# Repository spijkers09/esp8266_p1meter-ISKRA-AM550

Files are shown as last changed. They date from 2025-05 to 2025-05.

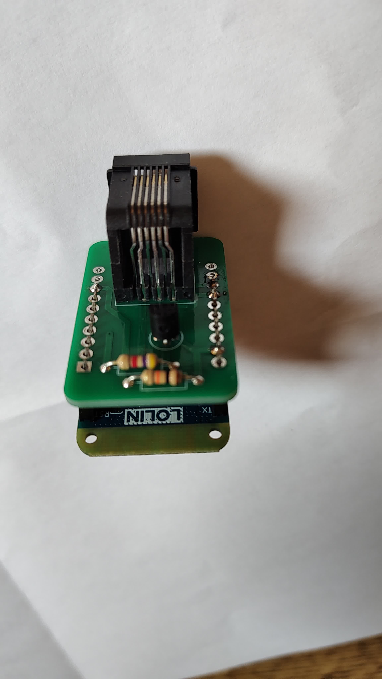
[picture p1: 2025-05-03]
assets/pic01.jpeg

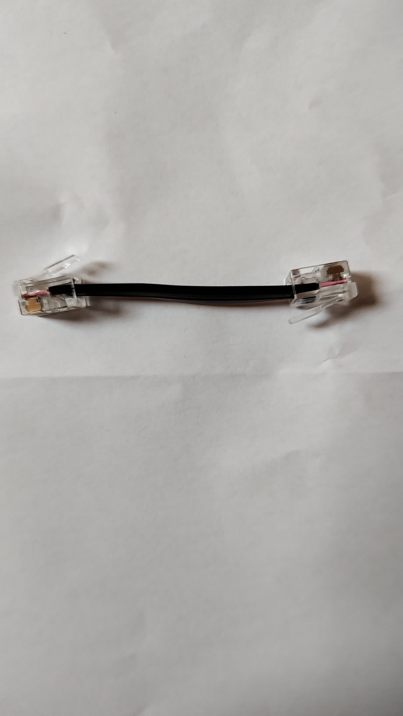
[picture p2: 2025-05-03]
assets/pic02.jpeg

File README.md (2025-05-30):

# esp8266_p1meter for ISKRA AM550

Software for the ESP2866 that sends P1 smart meter data to a mqtt broker, specifically adjusted for ISKRA AM550. The software changes are limited (removed the inversion). The hardware is updated big time. 

## about this fork
This fork (tries) to add support for the `ISKRA AM550` smartmeter (DSMR5.0). It is based on the fork by Daniel Jong https://github.com/daniel-jong/esp8266_p1meter. It also used some of the info from https://github.com/psvanstrom/esphome-p1reader

3 April 2025: Its working on a breadboard, but I ordered PCB to make a compact version and will create a 3D printable box.

2 May 2025: After some delay I received the PCB I designed. Turned out the bases I used was not entirely accurate, so it was 2 mm wider then the ESP8266. I have changed the design of the PCB to match the ESP8266. The correct design is in the directory.
If you want to use a breadboard, use the schematic.pdf

BE AWARE: I lost 1 ESP8266 because I soldered the PCB directly to the ESP before I had uploaded the software. Not sure why, but then upload is no longer working. Make sure you use the provided pinheaders to make it detachable. That will also provide future update possibilities.

The original source has issues with DSMR5.0 meters who like to send telegrams every 1 second at a high 115200 baud rate. 
This causes the used SoftwareSerial to struggle to keep up and thus only receives corrupted messages. This fork switches to using the main Hardware serial port (RX) for communication with the meter.

# Getting started
This setup requires:
- An esp8266 (I used Wemos d1 mini V4 with USB-C)
- A 10k ohm resistor
- A 4,7k ohm resistor
- A BC547 NPN transistor
- A modular RJ12 jack (see datablad)
- A [6 pin RJ12 cable]

Compiling up using Arduino IDE: 
I will try and extend this section, as it was the first time I actually did something with IDE.
- Ensure you have selected the right board. I selected LOLIN (Wemos) D1 Mini (clone)
- Using the Tools->Manage Libraries... install `PubSubClient (by Nick)` and `WifiManager (by tzapu)`. I installed several other libraries (at Arduino's request, for example ESP82266Autowifi)
- Verify the software. This should indicate errors (like missing functions/libraries)
- Connect the board to your computer. Under <Tools>/Com port select the correct port. For some reason it showed 2 in my case, then just try to select one.
- If the upload does not work, select the other
- Upload the software

I removed the PlatformIO version as I have no experience and have not used it. Please refer to the origin of this fork if you want to use it.

Finishing off:
- You should now see a new wifi network `ESP******` connect to this wifi network, a popup should appear, else manually navigate to `192.168.4.1`
- Configure your wifi and Mqtt settings
- It is usefull to create a separate user in HomeAssistant for MQTT. I created the user mqttuser and gave a password.
- The mqtt host adress is your homeassistant IP and use 1883 for the port.
- You can use the serial monitor function of Arduino IDE (also under <Tools>) to see the ESP waking up and trying to connect.
- To check if everything is up and running you can listen to the MQTT topic `hass/status`, on startup a single message is sent.

## Connecting to the P1 meter
Connect the esp8266 to an RJ12 cable/connector following the diagram.

2 May 2025: Schematic.pdf is the electrical schematic. You can use it wire a breadboard. P1meterv2.kicad_pcb is the updated file I used to order the PCB.
It uses the open source KiCad software.
The datablad PDF suggests a modular jack to use.

BE AWARE: most jacks are reversed (locking clip below/at PCB side). I used the wrong, reversed one (see the pictures in the assets directory), so I had to rotate 1 of the connectors 180. Which means a standard RJ12 cable will not work with the setup. Either order a correct jack or an RJ12 shrink tool.

## Box

30 May 2025: I found a really great tool to create a 3D box for PCB's. As mine is a stacked one, I had to fiddle with the settings to make it fit. It only took me 2 runs to create the perfect box.

This is the website of the creator of the tool. There is some explanation how to use it.

https://willem.aandewiel.nl/index.php/2022/01/02/yet-another-parametric-projectbox-generator/

The download location of the tool
https://github.com/mrWheel/YAPP_Box

The download location of the program used
https://openscad.org/downloads.html

In the assets I uploaded the tool as a zip (YAPP) and the source file of my box.

## Data Sent

All metrics are send to their own MQTT topic.
The software sends out to the following MQTT topics:

```
sensors/power/p1meter/consumption_low_tarif 2209397
sensors/power/p1meter/consumption_high_tarif 1964962
sensors/power/p1meter/returndelivery_low_tarif 2209397
sensors/power/p1meter/returndelivery_high_tarif 1964962
sensors/power/p1meter/actual_consumption 313
sensors/power/p1meter/actual_returndelivery 0
sensors/power/p1meter/l1_instant_power_usage 313
sensors/power/p1meter/l2_instant_power_usage 0
sensors/power/p1meter/l3_instant_power_usage 0
sensors/power/p1meter/l1_instant_power_current 1000
sensors/power/p1meter/l2_instant_power_current 0
sensors/power/p1meter/l3_instant_power_current 0
sensors/power/p1meter/l1_voltage 233
sensors/power/p1meter/l2_voltage 0
sensors/power/p1meter/l3_voltage 0
sensors/power/p1meter/gas_meter_m3 968922
sensors/power/p1meter/actual_tarif_group 2
sensors/power/p1meter/short_power_outages 3
sensors/power/p1meter/long_power_outages 1
sensors/power/p1meter/short_power_drops 0
sensors/power/p1meter/short_power_peaks 0
```

## Home Assistant Configuration

Use this [example](https://raw.githubusercontent.com/spijkers09/esp8266_p1meter-ISKRA-AM550/master/assets/p1_sensors.yaml) for home assistant's `sensor.yaml`

The automations are yours to create.
And always remember that sending alerts in case of a power outtage only make sense when you own a UPS battery :)

## Thanks to

This sketch is mostly copied and pasted from several other projects.
Standing on the heads of giants, big thanks and great respect to the writers and/or creators of:

- https://github.com/jantenhove/P1-Meter-ESP8266
- https://github.com/neographikal/P1-Meter-ESP8266-MQTT
- http://gejanssen.com/howto/Slimme-meter-uitlezen/
- https://github.com/rroethof/p1reader/
- http://romix.macuser.nl/software.html
- http://blog.regout.info/category/slimmeter/
- http://domoticx.com/p1-poort-slimme-meter-hardware/

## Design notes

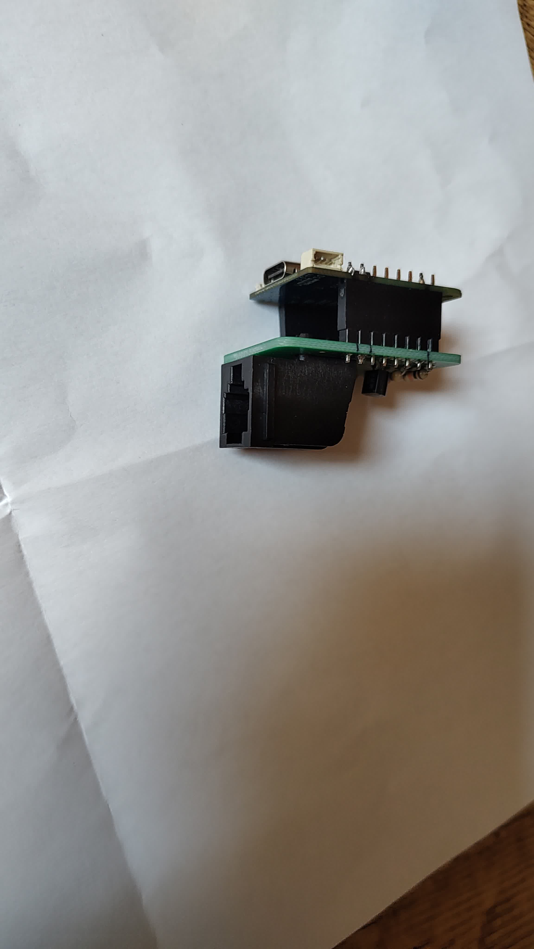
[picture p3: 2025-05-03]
assets/pic04.jpeg

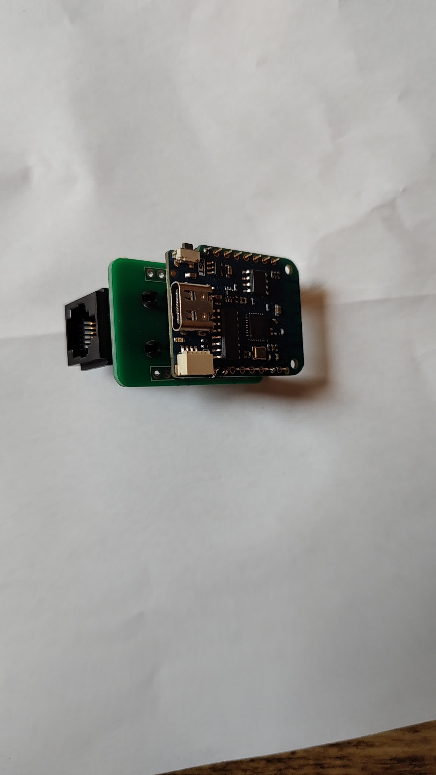
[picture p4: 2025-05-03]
assets/pic03.jpeg

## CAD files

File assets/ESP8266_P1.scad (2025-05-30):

//-----------------------------------------------------------------------
// Yet Another Parameterized Projectbox generator
//
//  This is a box for <template>
//
//  Version 3.1.2 (2024-04-16)
//
// This design is parameterized based on the size of a PCB.
//
// For many/complex cutoutGrills, you might need to adjust
//  the max number of elements in OpenSCAD:
//
//      Preferences->Advanced->Turn off rendering at 250000 elements
//                                                   ^^^^^^
//
//-----------------------------------------------------------------------

include <./YAPPgenerator_v3.scad>

//---------------------------------------------------------
// This design is parameterized based on the size of a PCB.
//---------------------------------------------------------
// Note: length/lengte refers to X axis, 
//       width/breedte refers to Y axis,
//       height/hoogte refers to Z axis

/*
      padding-back|<------pcb length --->|<padding-front
                            RIGHT
        0    X-axis ---> 
        +----------------------------------------+   ---
        |                                        |    ^
        |                                        |   padding-right 
      Y |                                        |    v
      | |    -5,y +----------------------+       |   ---              
 B    a |         | 0,y              x,y |       |     ^              F
 A    x |         |                      |       |     |              R
 C    i |         |                      |       |     | pcb width    O
 K    s |         |                      |       |     |              N
        |         | 0,0              x,0 |       |     v              T
      ^ |    -5,0 +----------------------+       |   ---
      | |                                        |    padding-left
      0 +----------------------------------------+   ---
        0    X-as --->
                          LEFT
*/


//-- which part(s) do you want to print?
printBaseShell        = true;
printLidShell         = true;
printSwitchExtenders  = true;
printDisplayClips     = true;

// ********************************************************************
// The Following will be used as the first element in the pbc array

//Defined here so you can define the "Main" PCB using these if wanted
pcbLength           = 35; // front to back (X axis) was 40
pcbWidth            = 26; // side to side (Y axis)
pcbThickness        = 1.6; 
standoffHeight      = 4.0; //-- How much the PCB needs to be raised from the base to leave room for solderings and whatnot
standoffDiameter    = 4;
standoffPinDiameter = 2.4;
standoffHoleSlack   = 0.4;

//===================================================================
// *** PCBs ***
// Printed Circuit Boards
//-------------------------------------------------------------------
//  Default origin =  yappCoordPCB : yappCoordBoxInside[0,0,0]
//
//  Parameters:
//   Required:
//    p(0) = name
//    p(1) = length
//    p(2) = width
//    p(3) = posx
//    p(4) = posy
//    p(5) = Thickness
//    p(6) = standoff_Height
//    p(7) = standoff_Diameter
//    p(8) = standoff_PinDiameter
//   Optional:
//    p(9) = standoff_HoleSlack (default to 0.4)

//The following can be used to get PCB values elsewhere in the script - not in pcb definition. 
//If "PCB Name" is omitted then "Main" is used
//  pcbLength           --> pcbLength("PCB Name")
//  pcbWidth            --> pcbWidth("PCB Name")
//  pcbThickness        --> pcbThickness("PCB Name") 
//  standoffHeight      --> standoffHeight("PCB Name") 
//  standoffDiameter    --> standoffDiameter("PCB Name") 
//  standoffPinDiameter --> standoffPinDiameter("PCB Name") 
//  standoffHoleSlack   --> standoffHoleSlack("PCB Name") 

pcb = 
[
  // Default Main PCB - DO NOT REMOVE the "Main" line.
  ["Main",              pcbLength,pcbWidth,    0,0,    pcbThickness,  standoffHeight, standoffDiameter, standoffPinDiameter, standoffHoleSlack]
];

//-------------------------------------------------------------------                            
//-- padding between pcb and inside wall
paddingFront        = 4.6;
paddingBack         = 1;
paddingRight        = 1.5;
paddingLeft         = 1.5;

//-- Edit these parameters for your own box dimensions
wallThickness       = 1.5;
basePlaneThickness  = 1.0;
lidPlaneThickness   = 1.0;

//-- Total height of box = lidPlaneThickness 
//                       + lidWallHeight 
//--                     + baseWallHeight 
//                       + basePlaneThickness
//-- space between pcb and lidPlane :=
//--      (bottonWallHeight+lidWallHeight) - (standoffHeight+pcbThickness)
baseWallHeight      = 32;
lidWallHeight       = 8;

//-- ridge where base and lid off box can overlap
//-- Make sure this isn't less than lidWallHeight
ridgeHeight         = 5.0;
ridgeSlack          = 0.2;
roundRadius         = 3.0;


// Set the layer height of your printer
printerLayerHeight  = 0.2;


//---------------------------
//--     C O N T R O L     --
//---------------------------
// -- Render --
renderQuality             = 8;          //-> from 1 to 32, Default = 8

// --Preview --
previewQuality            = 5;          //-> from 1 to 32, Default = 5
showSideBySide            = true;       //-> Default = true
onLidGap                  = 0;  // tip don't override to animate the lid opening
colorLid                  = "YellowGreen";   
alphaLid                  = 1;
colorBase                 = "BurlyWood";
alphaBase                 = 1;
hideLidWalls              = false;      //-> Remove the walls from the lid : only if preview and showSideBySide=true 
hideBaseWalls             = false;      //-> Remove the walls from the base : only if preview and showSideBySide=true  
showOrientation           = true;       //-> Show the Front/Back/Left/Right labels : only in preview
showPCB                   = false;      //-> Show the PCB in red : only in preview 
showSwitches              = false;      //-> Show the switches (for pushbuttons) : only in preview 
showButtonsDepressed      = false;      //-> Should the buttons in the Lid On view be in the pressed position
showOriginCoordBox        = false;      //-> Shows red bars representing the origin for yappCoordBox : only in preview 
showOriginCoordBoxInside  = false;      //-> Shows blue bars representing the origin for yappCoordBoxInside : only in preview 
showOriginCoordPCB        = false;      //-> Shows blue bars representing the origin for yappCoordBoxInside : only in preview 
showMarkersPCB            = false;      //-> Shows black bars corners of the PCB : only in preview 
showMarkersCenter         = false;      //-> Shows magenta bars along the centers of all faces  
inspectX                  = 0;          //-> 0=none (>0 from Back)
inspectY                  = 0;          //-> 0=none (>0 from Right)
inspectZ                  = 0;          //-> 0=none (>0 from Bottom)
inspectXfromBack          = true;       //-> View from the inspection cut foreward
inspectYfromLeft          = true;       //-> View from the inspection cut to the right
inspectZfromBottom        = true;       //-> View from the inspection cut up
//---------------------------
//--     C O N T R O L     --
//---------------------------

//-------------------------------------------------------------------
//-------------------------------------------------------------------
// Start of Debugging config (used if not overridden in template)
// ------------------------------------------------------------------
// ------------------------------------------------------------------

//==================================================================
//  *** Shapes ***
//------------------------------------------------------------------
//  There are a view pre defines shapes and masks
//  shapes:
//      shapeIsoTriangle, shapeHexagon, shape6ptStar
//
//  masks:
//      maskHoneycomb, maskHexCircles, maskBars, maskOffsetBars
//
//------------------------------------------------------------------
// Shapes should be defined to fit into a 1x1 box (+/-0.5 in X and Y) - they will 
// be scaled as needed.
// defined as a vector of [x,y] vertices pairs.(min 3 vertices)
// for example a triangle could be [yappPolygonDef,[[-0.5,-0.5],[0,0.5],[0.5,-0.5]]];
// To see how to add your own shapes and mask see the YAPPgenerator program
//------------------------------------------------------------------


// Show sample of a Mask
//SampleMask(maskHoneycomb);
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

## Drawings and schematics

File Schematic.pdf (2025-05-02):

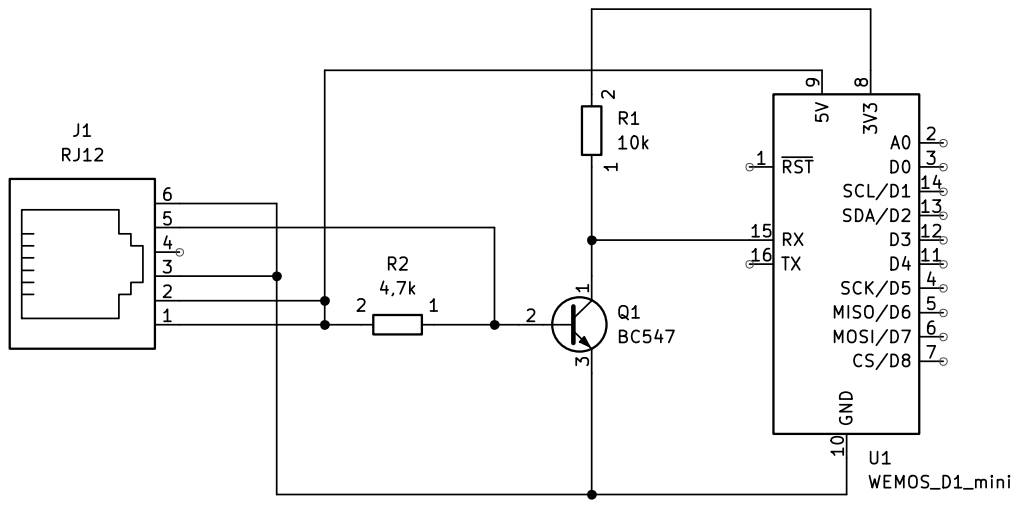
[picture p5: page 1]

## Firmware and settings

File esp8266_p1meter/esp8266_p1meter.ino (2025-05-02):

#include <FS.h>
#include <EEPROM.h>
#include <DNSServer.h>
#include <ESP8266WiFi.h>
#include <Ticker.h>
#include <WiFiManager.h>
#include <ESP8266mDNS.h>
#include <WiFiUdp.h>
#include <ArduinoOTA.h>
#include <PubSubClient.h>

// * Include settings
#include "settings.h"

// * Initiate led blinker library
Ticker ticker;

// * Initiate WIFI client
WiFiClient espClient;

// * Initiate MQTT client
PubSubClient mqtt_client(espClient);

// **********************************
// * WIFI                           *
// **********************************

// * Gets called when WiFiManager enters configuration mode
void configModeCallback(WiFiManager *myWiFiManager)
{
    Serial.println(F("Entered config mode"));
    Serial.println(WiFi.softAPIP());

    // * If you used auto generated SSID, print it
    Serial.println(myWiFiManager->getConfigPortalSSID());

    // * Entered config mode, make led toggle faster
    ticker.attach(0.2, tick);
}

// **********************************
// * Ticker (System LED Blinker)    *
// **********************************

// * Blink on-board Led
void tick()
{
    // * Toggle state
    int state = digitalRead(LED_BUILTIN);    // * Get the current state of GPIO1 pin
    digitalWrite(LED_BUILTIN, !state);       // * Set pin to the opposite state
}

// **********************************
// * MQTT                           *
// **********************************

// * Send a message to a broker topic
void send_mqtt_message(const char *topic, char *payload)
{
    Serial.printf("MQTT Outgoing on %s: ", topic);
    Serial.println(payload);

    bool result = mqtt_client.publish(topic, payload, false);

    if (!result)
    {
        Serial.printf("MQTT publish to topic %s failed\n", topic);
    }
}

// * Reconnect to MQTT server and subscribe to in and out topics
bool mqtt_reconnect()
{
    // * Loop until we're reconnected
    int MQTT_RECONNECT_RETRIES = 0;

    while (!mqtt_client.connected() && MQTT_RECONNECT_RETRIES < MQTT_MAX_RECONNECT_TRIES)
    {
        MQTT_RECONNECT_RETRIES++;
        Serial.printf("MQTT connection attempt %d / %d ...\n", MQTT_RECONNECT_RETRIES, MQTT_MAX_RECONNECT_TRIES);

        // * Attempt to connect
        if (mqtt_client.connect(HOSTNAME, MQTT_USER, MQTT_PASS))
        {
            Serial.println(F("MQTT connected!"));

            // * Once connected, publish an announcement...

            mqtt_client.publish("hass/status", "p1 meter alive: " HOSTNAME);

            Serial.printf("MQTT root topic: %s\n", MQTT_ROOT_TOPIC);
        }
        else
        {
            Serial.print(F("MQTT Connection failed: rc="));
            Serial.println(mqtt_client.state());
            Serial.println(F(" Retrying in 5 seconds"));
            Serial.println("");

            // * Wait 5 seconds before retrying
            delay(5000);
        }
    }

    if (MQTT_RECONNECT_RETRIES >= MQTT_MAX_RECONNECT_TRIES)
    {
        Serial.printf("*** MQTT connection failed, giving up after %d tries ...\n", MQTT_RECONNECT_RETRIES);
        return false;
    }

    return true;
}

void send_metric(String name, long metric)
{
    Serial.print(F("Sending metric to broker: "));
    Serial.print(name);
    Serial.print(F("="));
    Serial.println(metric);

    char output[10];
    ltoa(metric, output, sizeof(output));

    String topic = String(MQTT_ROOT_TOPIC) + "/" + name;
    send_mqtt_message(topic.c_str(), output);
}

void send_data_to_broker()
{
    send_metric("consumption_low_tarif", CONSUMPTION_LOW_TARIF);
    send_metric("consumption_high_tarif", CONSUMPTION_HIGH_TARIF);
    send_metric("returndelivery_low_tarif", RETURNDELIVERY_LOW_TARIF);
    send_metric("returndelivery_high_tarif", RETURNDELIVERY_HIGH_TARIF);
    send_metric("actual_consumption", ACTUAL_CONSUMPTION);
    send_metric("actual_returndelivery", ACTUAL_RETURNDELIVERY);

    send_metric("l1_instant_power_usage", L1_INSTANT_POWER_USAGE);
    send_metric("l2_instant_power_usage", L2_INSTANT_POWER_USAGE);
    send_metric("l3_instant_power_usage", L3_INSTANT_POWER_USAGE);
    send_metric("l1_instant_power_current", L1_INSTANT_POWER_CURRENT);
    send_metric("l2_instant_power_current", L2_INSTANT_POWER_CURRENT);
    send_metric("l3_instant_power_current", L3_INSTANT_POWER_CURRENT);
    send_metric("l1_voltage", L1_VOLTAGE);
    send_metric("l2_voltage", L2_VOLTAGE);
    send_metric("l3_voltage", L3_VOLTAGE);
    
    send_metric("gas_meter_m3", GAS_METER_M3);

    send_metric("actual_tarif_group", ACTUAL_TARIF);
    send_metric("short_power_outages", SHORT_POWER_OUTAGES);
    send_metric("long_power_outages", LONG_POWER_OUTAGES);
    send_metric("short_power_drops", SHORT_POWER_DROPS);
    send_metric("short_power_peaks", SHORT_POWER_PEAKS);
}

// **********************************
// * P1                             *
// **********************************

unsigned int CRC16(unsigned int crc, unsigned char *buf, int len)
{
	for (int pos = 0; pos < len; pos++)
    {
		crc ^= (unsigned int)buf[pos];    // * XOR byte into least sig. byte of crc
                                          // * Loop over each bit
        for (int i = 8; i != 0; i--)
        {
            // * If the LSB is set
            if ((crc & 0x0001) != 0)
            {
                // * Shift right and XOR 0xA001
                crc >>= 1;
				crc ^= 0xA001;
			}
            // * Else LSB is not set
            else
                // * Just shift right
                crc >>= 1;
		}
	}
	return crc;
}

bool isNumber(char *res, int len)
{
    for (int i = 0; i < len; i++)
    {
        if (((res[i] < '0') || (res[i] > '9')) && (res[i] != '.' && res[i] != 0))
            return false;
    }
    return true;
}

int FindCharInArrayRev(char array[], char c, int len)
{
    for (int i = len - 1; i >= 0; i--)
    {
        if (array[i] == c)
            return i;
    }
    return -1;
}

long getValue(char *buffer, int maxlen, char startchar, char endchar)
{
    int s = FindCharInArrayRev(buffer, startchar, maxlen - 2);
    int l = FindCharInArrayRev(buffer, endchar, maxlen - 2) - s - 1;

    char res[16];
    memset(res, 0, sizeof(res));

    if (strncpy(res, buffer + s + 1, l))
    {
        if (endchar == '*')
        {
            if (isNumber(res, l))
                // * Lazy convert float to long
                return (1000 * atof(res));
        }
        else if (endchar == ')')
        {
            if (isNumber(res, l))
                return atof(res);
        }
    }
    return 0;
}

bool decode_telegram(int len)
{
    int startChar = FindCharInArrayRev(telegram, '/', len);
    int endChar = FindCharInArrayRev(telegram, '!', len);
    bool validCRCFound = false;

    for (int cnt = 0; cnt < len; cnt++) {
        Serial.print(telegram[cnt]);
    }
    Serial.print("\n");

    if (startChar >= 0)
    {
        // * Start found. Reset CRC calculation
        currentCRC = CRC16(0x0000,(unsigned char *) telegram+startChar, len-startChar);
    }
    else if (endChar >= 0)
    {
        // * Add to crc calc
        currentCRC = CRC16(currentCRC,(unsigned char*)telegram+endChar, 1);

        char messageCRC[5];
        strncpy(messageCRC, telegram + endChar + 1, 4);

        messageCRC[4] = 0;   // * Thanks to HarmOtten (issue 5)
        validCRCFound = (strtol(messageCRC, NULL, 16) == currentCRC);

        if (validCRCFound)
            Serial.println(F("CRC Valid!"));
        else
            Serial.println(F("CRC Invalid!"));

        currentCRC = 0;
    }
    else
    {
        currentCRC = CRC16(currentCRC, (unsigned char*) telegram, len);
    }

    // 1-0:1.8.1(000992.992*kWh)
    // 1-0:1.8.1 = Elektra verbruik laag tarief (DSMR v4.0)
    if (strncmp(telegram, "1-0:1.8.1", strlen("1-0:1.8.1")) == 0)
    {
        CONSUMPTION_LOW_TARIF = getValue(telegram, len, '(', '*');
    }

    // 1-0:1.8.2(000560.157*kWh)
    // 1-0:1.8.2 = Elektra verbruik hoog tarief (DSMR v4.0)
    if (strncmp(telegram, "1-0:1.8.2", strlen("1-0:1.8.2")) == 0)
    {
        CONSUMPTION_HIGH_TARIF = getValue(telegram, len, '(', '*');
    }
	
    // 1-0:2.8.1(000560.157*kWh)
    // 1-0:2.8.1 = Elektra teruglevering laag tarief (DSMR v4.0)
    if (strncmp(telegram, "1-0:2.8.1", strlen("1-0:2.8.1")) == 0)
    {
        RETURNDELIVERY_LOW_TARIF = getValue(telegram, len, '(', '*');
    }

    // 1-0:2.8.2(000560.157*kWh)
    // 1-0:2.8.2 = Elektra teruglevering hoog tarief (DSMR v4.0)
    if (strncmp(telegram, "1-0:2.8.2", strlen("1-0:2.8.2")) == 0)
    {
        RETURNDELIVERY_HIGH_TARIF = getValue(telegram, len, '(', '*');
    }

    // 1-0:1.7.0(00.424*kW) Actueel verbruik
    // 1-0:1.7.x = Electricity consumption actual usage (DSMR v4.0)
    if (strncmp(telegram, "1-0:1.7.0", strlen("1-0:1.7.0")) == 0)
    {
        ACTUAL_CONSUMPTION = getValue(telegram, len, '(', '*');
    }

    // 1-0:2.7.0(00.000*kW) Actuele teruglevering (-P) in 1 Watt resolution
    if (strncmp(telegram, "1-0:2.7.0", strlen("1-0:2.7.0")) == 0)
    {
        ACTUAL_RETURNDELIVERY = getValue(telegram, len, '(', '*');
    }

    // 1-0:21.7.0(00.378*kW)
    // 1-0:21.7.0 = Instantaan vermogen Elektriciteit levering L1
    if (strncmp(telegram, "1-0:21.7.0", strlen("1-0:21.7.0")) == 0)
    {
        L1_INSTANT_POWER_USAGE = getValue(telegram, len, '(', '*');
    }

    // 1-0:41.7.0(00.378*kW)
    // 1-0:41.7.0 = Instantaan vermogen Elektriciteit levering L2
    if (strncmp(telegram, "1-0:41.7.0", strlen("1-0:41.7.0")) == 0)
    {
        L2_INSTANT_POWER_USAGE = getValue(telegram, len, '(', '*');
    }

    // 1-0:61.7.0(00.378*kW)
    // 1-0:61.7.0 = Instantaan vermogen Elektriciteit levering L3
    if (strncmp(telegram, "1-0:61.7.0", strlen("1-0:61.7.0")) == 0)
    {
        L3_INSTANT_POWER_USAGE = getValue(telegram, len, '(', '*');
    }

    // 1-0:31.7.0(002*A)
    // 1-0:31.7.0 = Instantane stroom Elektriciteit L1
    if (strncmp(telegram, "1-0:31.7.0", strlen("1-0:31.7.0")) == 0)
    {
        L1_INSTANT_POWER_CURRENT = getValue(telegram, len, '(', '*');
    }
    // 1-0:51.7.0(002*A)
    // 1-0:51.7.0 = Instantane stroom Elektriciteit L2
    if (strncmp(telegram, "1-0:51.7.0", strlen("1-0:51.7.0")) == 0)
    {
        L2_INSTANT_POWER_CURRENT = getValue(telegram, len, '(', '*');
    }
    // 1-0:71.7.0(002*A)
    // 1-0:71.7.0 = Instantane stroom Elektriciteit L3
    if (strncmp(telegram, "1-0:71.7.0", strlen("1-0:71.7.0")) == 0)
    {
        L3_INSTANT_POWER_CURRENT = getValue(telegram, len, '(', '*');
    }

    // 1-0:32.7.0(232.0*V)
    // 1-0:32.7.0 = Voltage L1
    if (strncmp(telegram, "1-0:32.7.0", strlen("1-0:32.7.0")) == 0)
    {
        L1_VOLTAGE = getValue(telegram, len, '(', '*');
    }
    // 1-0:52.7.0(232.0*V)
    // 1-0:52.7.0 = Voltage L2
    if (strncmp(telegram, "1-0:52.7.0", strlen("1-0:52.7.0")) == 0)
    {
        L2_VOLTAGE = getValue(telegram, len, '(', '*');
    }   
    // 1-0:72.7.0(232.0*V)
    // 1-0:72.7.0 = Voltage L3
    if (strncmp(telegram, "1-0:72.7.0", strlen("1-0:72.7.0")) == 0)
    {
        L3_VOLTAGE = getValue(telegram, len, '(', '*');
    }

    // 0-1:24.2.1(150531200000S)(00811.923*m3)
    // 0-1:24.2.1 = Gas (DSMR v4.0) on Kaifa MA105 meter
    if (strncmp(telegram, "0-1:24.2.1", strlen("0-1:24.2.1")) == 0)
    {
        GAS_METER_M3 = getValue(telegram, len, '(', '*');
    }

    // 0-0:96.14.0(0001)
    // 0-0:96.14.0 = Actual Tarif
    if (strncmp(telegram, "0-0:96.14.0", strlen("0-0:96.14.0")) == 0)
    {
        ACTUAL_TARIF = getValue(telegram, len, '(', ')');
    }

    // 0-0:96.7.21(00003)
    // 0-0:96.7.21 = Aantal onderbrekingen Elektriciteit
    if (strncmp(telegram, "0-0:96.7.21", strlen("0-0:96.7.21")) == 0)
    {
        SHORT_POWER_OUTAGES = getValue(telegram, len, '(', ')');
    }

    // 0-0:96.7.9(00001)
    // 0-0:96.7.9 = Aantal lange onderbrekingen Elektriciteit
    if (strncmp(telegram, "0-0:96.7.9", strlen("0-0:96.7.9")) == 0)
    {
        LONG_POWER_OUTAGES = getValue(telegram, len, '(', ')');
    }

    // 1-0:32.32.0(00000)
    // 1-0:32.32.0 = Aantal korte spanningsdalingen Elektriciteit in fase 1
    if (strncmp(telegram, "1-0:32.32.0", strlen("1-0:32.32.0")) == 0)
    {
        SHORT_POWER_DROPS = getValue(telegram, len, '(', ')');
    }

    // 1-0:32.36.0(00000)
    // 1-0:32.36.0 = Aantal korte spanningsstijgingen Elektriciteit in fase 1
    if (strncmp(telegram, "1-0:32.36.0", strlen("1-0:32.36.0")) == 0)
    {
        SHORT_POWER_PEAKS = getValue(telegram, len, '(', ')');
    }

    return validCRCFound;
}

void read_p1_hardwareserial()
{
    if (Serial.available())
    {
        memset(telegram, 0, sizeof(telegram));

        while (Serial.available())
        {
            ESP.wdtDisable();
            int len = Serial.readBytesUntil('\n', telegram, P1_MAXLINELENGTH);
            ESP.wdtEnable(1);

            processLine(len);
        }
    }
}

void processLine(int len) {
    telegram[len] = '\n';
    telegram[len + 1] = 0;
    yield();

    bool result = decode_telegram(len + 1);
    if (result) {
        send_data_to_broker();
        LAST_UPDATE_SENT = millis();
    }
}

// **********************************
// * EEPROM helpers                 *
// **********************************

String read_eeprom(int offset, int len)
{
    Serial.print(F("read_eeprom()"));

    String res = "";
    for (int i = 0; i < len; ++i)
    {
        res += char(EEPROM.read(i + offset));
    }
    return res;
}

void write_eeprom(int offset, int len, String value)
{
    Serial.println(F("write_eeprom()"));
    for (int i = 0; i < len; ++i)
    {
        if ((unsigned)i < value.length())
        {
            EEPROM.write(i + offset, value[i]);
        }
        else
        {
            EEPROM.write(i + offset, 0);
        }
    }
}

// ******************************************
// * Callback for saving WIFI config        *
// ******************************************

bool shouldSaveConfig = false;

// * Callback notifying us of the need to save config
void save_wifi_config_callback ()
{
    Serial.println(F("Should save config"));
    shouldSaveConfig = true;
}


// **********************************
// * Setup MDNS discovery service   *
// **********************************

void setup_mdns()
{
    Serial.println(F("Starting MDNS responder service"));

    bool mdns_result = MDNS.begin(HOSTNAME);
    if (mdns_result)
    {
        MDNS.addService("http", "tcp", 80);
    }
}

// **********************************
// * Setup Main                     *
// **********************************

void setup()
{
    // * Configure EEPROM
    EEPROM.begin(512);

    // Setup a hw serial connection for communication with the P1 meter and logging (not using inversion)
    Serial.begin(BAUD_RATE, SERIAL_8N1, SERIAL_FULL);
    Serial.setRxBufferSize(1024);
    Serial.println("");
    Serial.println("Swapping UART0 RX to inverted");
    Serial.flush();

    // Invert the RX serialport by setting a register value, this way the TX might continue normally allowing the serial monitor to read println's
   // USC0(UART0) = USC0(UART0) | BIT(UCRXI);
    Serial.println("Serial port is ready to recieve.");

    // * Set led pin as output
    pinMode(LED_BUILTIN, OUTPUT);

    // * Start ticker with 0.5 because we start in AP mode and try to connect
    ticker.attach(0.6, tick);

    // * Get MQTT Server settings
    String settings_available = read_eeprom(134, 1);

    if (settings_available == "1")
    {
        read_eeprom(0, 64).toCharArray(MQTT_HOST, 64);   // * 0-63
        read_eeprom(64, 6).toCharArray(MQTT_PORT, 6);    // * 64-69
        read_eeprom(70, 32).toCharArray(MQTT_USER, 32);  // * 70-101
        read_eeprom(102, 32).toCharArray(MQTT_PASS, 32); // * 102-133
    }

    WiFiManagerParameter CUSTOM_MQTT_HOST("host", "MQTT hostname", MQTT_HOST, 64);
    WiFiManagerParameter CUSTOM_MQTT_PORT("port", "MQTT port",     MQTT_PORT, 6);
    WiFiManagerParameter CUSTOM_MQTT_USER("user", "MQTT user",     MQTT_USER, 32);
    WiFiManagerParameter CUSTOM_MQTT_PASS("pass", "MQTT pass",     MQTT_PASS, 32);

    // * WiFiManager local initialization. Once its business is done, there is no need to keep it around
    WiFiManager wifiManager;

    // * Reset settings - uncomment for testing
    // wifiManager.resetSettings();

    // * Set callback that gets called when connecting to previous WiFi fails, and enters Access Point mode
    wifiManager.setAPCallback(configModeCallback);

    // * Set timeout
    wifiManager.setConfigPortalTimeout(WIFI_TIMEOUT);

    // * Set save config callback
    wifiManager.setSaveConfigCallback(save_wifi_config_callback);

    // * Add all your parameters here
    wifiManager.addParameter(&CUSTOM_MQTT_HOST);
    wifiManager.addParameter(&CUSTOM_MQTT_PORT);
    wifiManager.addParameter(&CUSTOM_MQTT_USER);
    wifiManager.addParameter(&CUSTOM_MQTT_PASS);

    // * Fetches SSID and pass and tries to connect
    // * Reset when no connection after 10 seconds
    if (!wifiManager.autoConnect())
    {
        Serial.println(F("Failed to connect to WIFI and hit timeout"));

        // * Reset and try again, or maybe put it to deep sleep
        ESP.reset();
        delay(WIFI_TIMEOUT);
    }

    // * Read updated parameters
    strcpy(MQTT_HOST, CUSTOM_MQTT_HOST.getValue());
    strcpy(MQTT_PORT, CUSTOM_MQTT_PORT.getValue());
    strcpy(MQTT_USER, CUSTOM_MQTT_USER.getValue());
    strcpy(MQTT_PASS, CUSTOM_MQTT_PASS.getValue());

    // * Save the custom parameters to FS
    if (shouldSaveConfig)
    {
        Serial.println(F("Saving WiFiManager config"));

        write_eeprom(0, 64, MQTT_HOST);   // * 0-63
        write_eeprom(64, 6, MQTT_PORT);   // * 64-69
        write_eeprom(70, 32, MQTT_USER);  // * 70-101
        write_eeprom(102, 32, MQTT_PASS); // * 102-133
        write_eeprom(134, 1, "1");        // * 134 --> always "1"
        EEPROM.commit();
    }

    // * If you get here you have connected to the WiFi
    Serial.println(F("Connected to WIFI..."));

    // * Keep LED on
    ticker.detach();
    digitalWrite(LED_BUILTIN, LOW);

    // * Configure OTA
    // setup_ota();

    // * Startup MDNS Service
    setup_mdns();

    // * Setup MQTT
    Serial.printf("MQTT connecting to: %s:%s\n", MQTT_HOST, MQTT_PORT);

    mqtt_client.setServer(MQTT_HOST, atoi(MQTT_PORT));

}

// **********************************
// * Loop                           *
// **********************************

void loop()
{
    // ArduinoOTA.handle();
    long now = millis();

    if (!mqtt_client.connected())
    {
        if (now - LAST_RECONNECT_ATTEMPT > 5000)
        {
            LAST_RECONNECT_ATTEMPT = now;

            if (mqtt_reconnect())
            {
                LAST_RECONNECT_ATTEMPT = 0;
            }
        }
    }
    else
    {
        mqtt_client.loop();
    }
    
    if (now - LAST_UPDATE_SENT > UPDATE_INTERVAL) {
        read_p1_hardwareserial();
    }
}

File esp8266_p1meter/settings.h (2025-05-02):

// **********************************
// * Settings                       *
// **********************************

// Update treshold in milliseconds, messages will only be sent on this interval
#define UPDATE_INTERVAL 60000  // 1 minute
//#define UPDATE_INTERVAL 300000 // 5 minutes

// * Baud rate for both hardware and software 
#define BAUD_RATE 115200

// The used serial pins, note that this can only be UART0, as other serial port doesn't support inversion
// By default the UART0 serial will be used. These settings displayed here just as a reference. 
// #define SERIAL_RX RX
// #define SERIAL_TX TX

// * Max telegram length
#define P1_MAXLINELENGTH 1050

// * The hostname of our little creature
#define HOSTNAME "p1meter"

// * Wifi timeout in milliseconds
#define WIFI_TIMEOUT 30000

// * MQTT network settings
#define MQTT_MAX_RECONNECT_TRIES 10

// * MQTT root topic
#define MQTT_ROOT_TOPIC "sensors/power/p1meter"

// * MQTT Last reconnection counter
long LAST_RECONNECT_ATTEMPT = 0;

long LAST_UPDATE_SENT = 0;

// * To be filled with EEPROM data
char MQTT_HOST[64] = "";
char MQTT_PORT[6]  = "";
char MQTT_USER[32] = "";
char MQTT_PASS[32] = "";

// * Set to store received telegram
char telegram[P1_MAXLINELENGTH];

// * Set to store the data values read
long CONSUMPTION_LOW_TARIF;
long CONSUMPTION_HIGH_TARIF;

long RETURNDELIVERY_LOW_TARIF;
long RETURNDELIVERY_HIGH_TARIF;

long ACTUAL_CONSUMPTION;
long ACTUAL_RETURNDELIVERY;
long GAS_METER_M3;

long L1_INSTANT_POWER_USAGE;
long L2_INSTANT_POWER_USAGE;
long L3_INSTANT_POWER_USAGE;
long L1_INSTANT_POWER_CURRENT;
long L2_INSTANT_POWER_CURRENT;
long L3_INSTANT_POWER_CURRENT;
long L1_VOLTAGE;
long L2_VOLTAGE;
long L3_VOLTAGE;

// Set to store data counters read
long ACTUAL_TARIF;
long SHORT_POWER_OUTAGES;
long LONG_POWER_OUTAGES;
long SHORT_POWER_DROPS;
long SHORT_POWER_PEAKS;

// * Set during CRC checking
unsigned int currentCRC = 0;

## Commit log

2023-09-04 Fix serial read issue on Belgian meters
    Fixes https://github.com/daniel-jong/esp8266_p1meter/issues/35
    [esp8266_p1meter.ino]
2023-10-27 Add note about 4 pin rj11 connectors
